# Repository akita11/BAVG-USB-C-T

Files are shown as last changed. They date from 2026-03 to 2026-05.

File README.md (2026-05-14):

# BAVG-USBC-T / BAVG-USBC-T-PD / BAVG-USBC-T-PDdiv

USB TypeｰCケーブル（両側）をツイストペア線と電源線として使用して、RS485等の差動伝送を行うことができます。
複数を直列（デージーチェーン）接続することで、マルチドロップのT型トポロジ接続にできます。

[M5Stack社のRS485 Unit](https://www.switch-science.com/products/6554)や[RS485M Unit](https://github.com/akita11/RS485M_Unit)等に接続して使用できます。
USB Type-Cケーブルの、データ線(D+/D-)をデータ送信用の差動対(A/B)、電源線を給電(V/G)に用います。

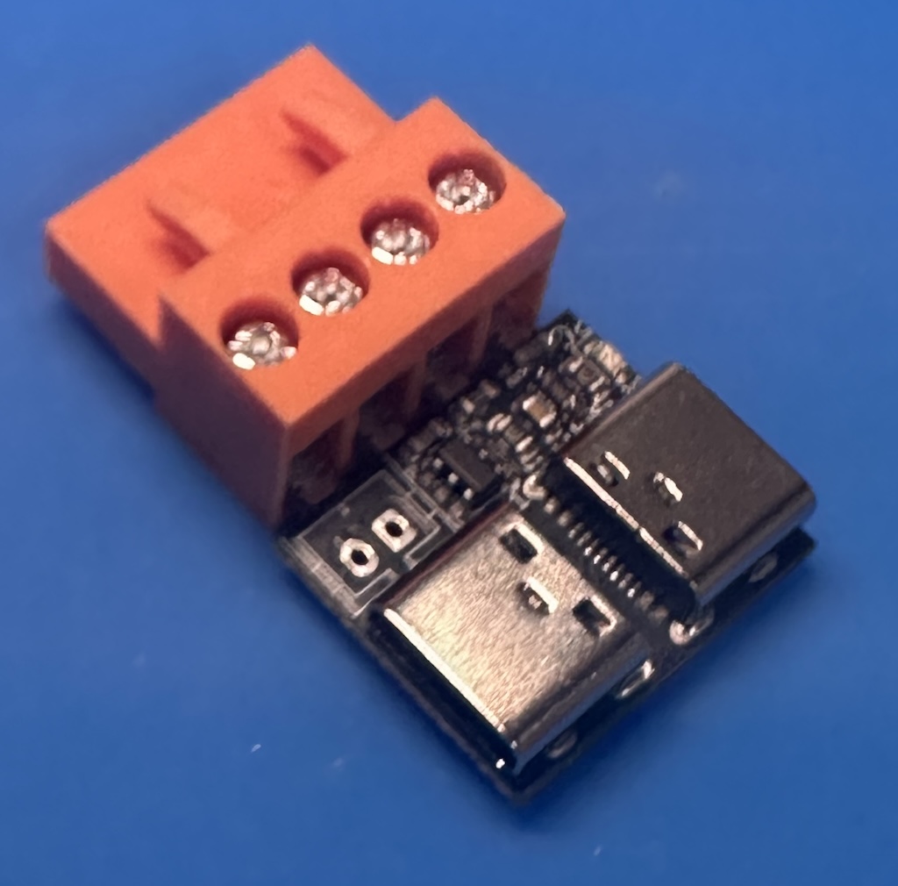
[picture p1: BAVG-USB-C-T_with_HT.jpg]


このページでは以下の3種類の情報をまとめています。

## BAVG-USBC-T

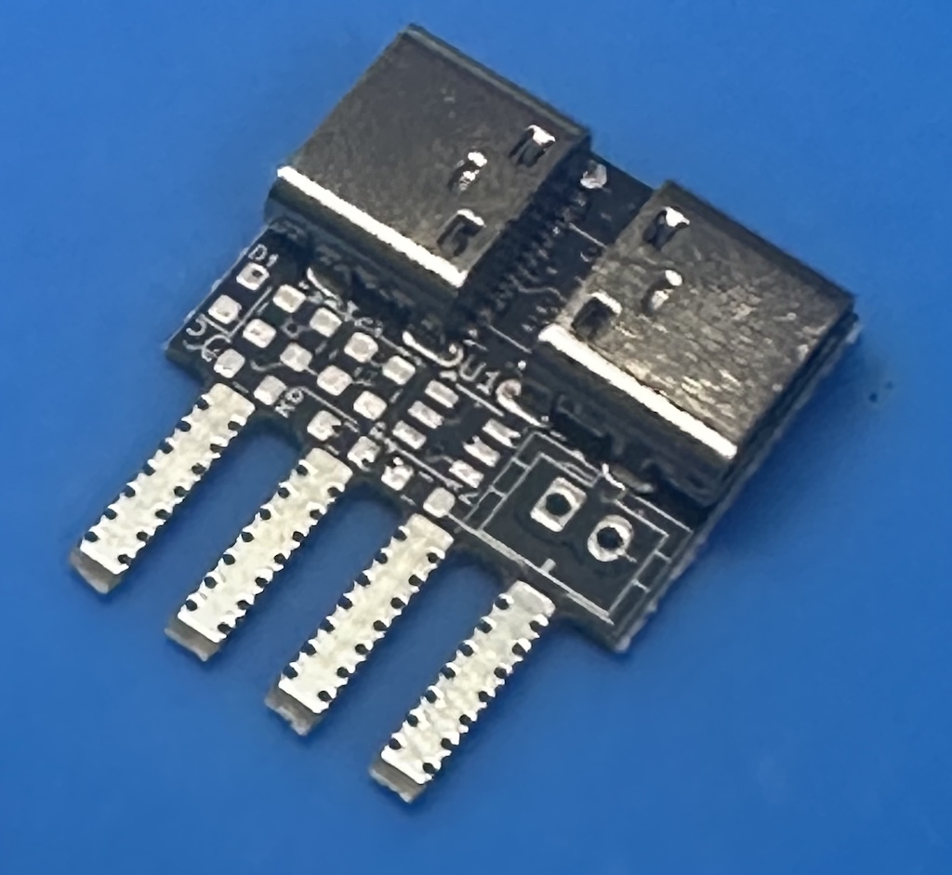
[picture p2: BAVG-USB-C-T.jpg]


両側のUSB Type-Cコネクタ間のデータ線(DP/DN)がA/B線と接続されていて、マルチドロップ型のデータ通信を行うことができます。

## BAVG-USBC-T-PD

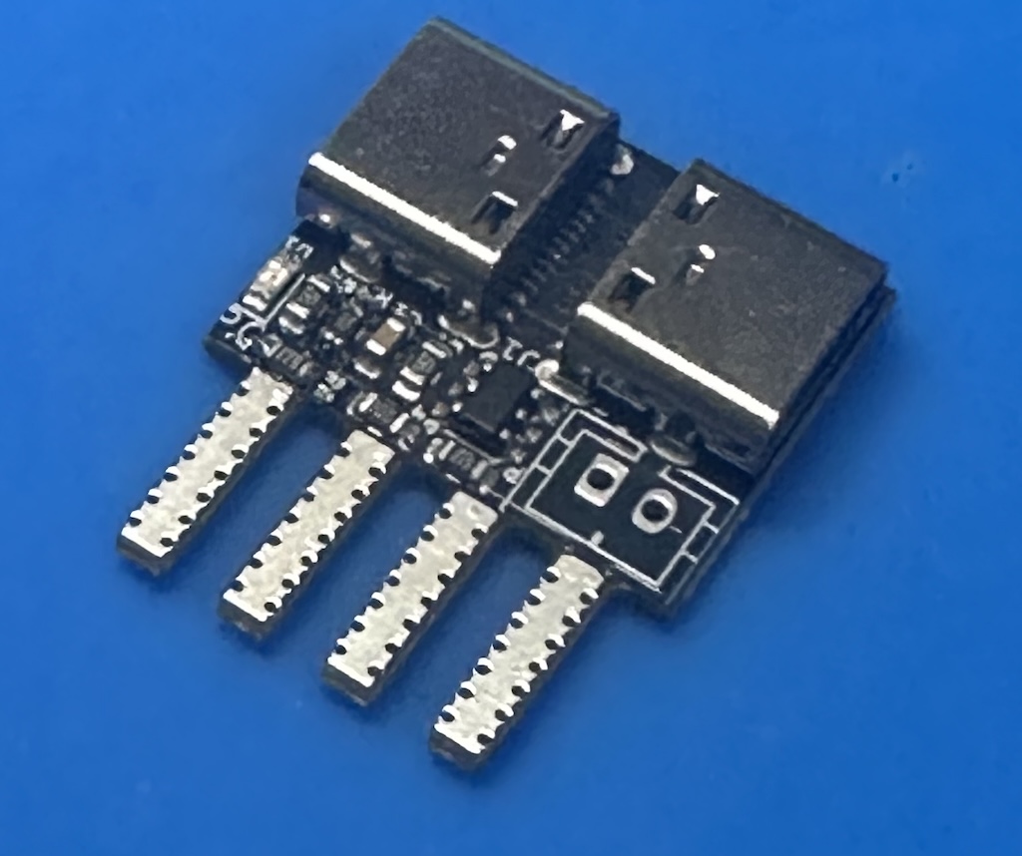
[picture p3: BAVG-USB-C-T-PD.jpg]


BAVG-USBC-T-PDではUSB PD (Power Derivery)の電圧設定機能があり、給電電圧を20Vまたは12Vに設定できます。
電圧設定が有効の場合はPG (Power Good)LEDが点灯します

また2つのUSBコネクタの通信線は接続されていないため、両側のUSBコネクタでのデータ通信を行うことはできません。
2つのコネクタでデータ通信を行う場合は、PD機能のない「BAVG-USBC-T」、またはPD給電コネクタが別にある「BAVG-USBC-T-PDdiv」を使用してください。

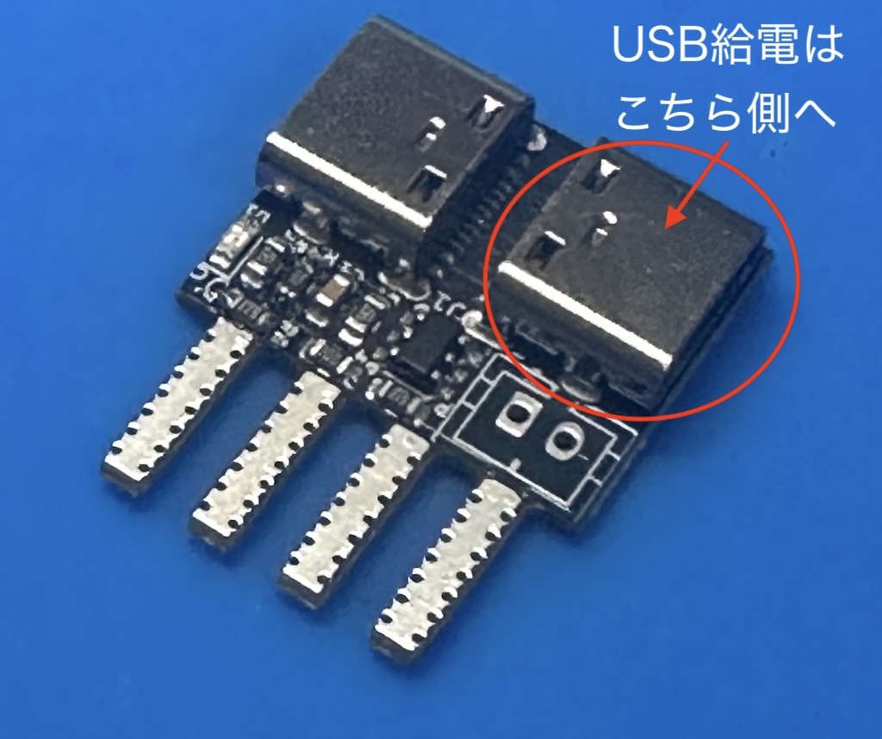
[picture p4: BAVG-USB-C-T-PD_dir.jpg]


**※USB PD電源からのUSB Type-Cケーブルは、必ず右側のUSB Type-Cコネクタ（この写真の赤丸側）へ接続してください。
（反対側に接続すると、RS485ラインのB/A端子がUSBケーブルのDP/DNに接続され、ACアダプタ等によってはQC制御によって供給電圧が変動する場合があり、高電圧の場合は機器が破損する場合があります）
またデータ通信は左側のUSB Type-Cコネクタのみに接続されています。**

通信経路と給電は以下の接続としてください。

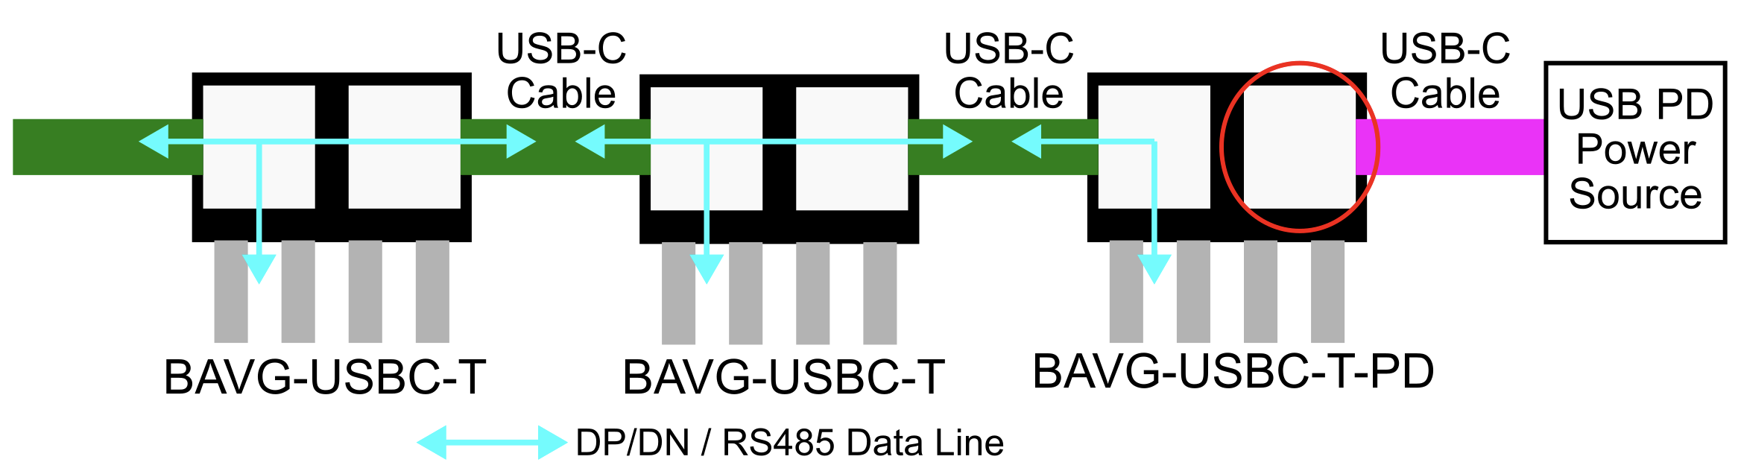
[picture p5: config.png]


### USB PD給電の設定

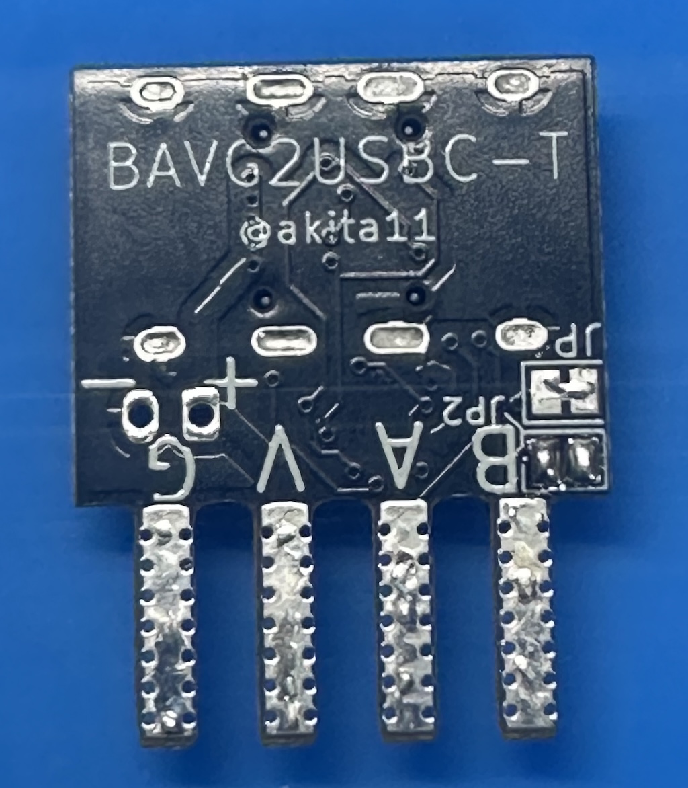
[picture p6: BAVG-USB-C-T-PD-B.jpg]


- JP1: USB PD電圧設定機能の有効無効設定
  - ショート（デフォルト） : 有効
  - オープン : =無効

- JP2でUSB PD給電電圧
  - オープン（デフォルト）: 20V
  - ショート : 12V

※USB PD電圧設定機能を有効にするのは、接続全体で1台のみとしてください。

※JP2の設定は、給電元（ACアダプタ等）へ要求する電圧で、実際に供給される電圧はUSB PD ACアダプタ等の仕様によります。
（例えば給電側の供給可能電圧が9V/15V/20Vの場合でJP2をショートした場合は9Vとなります）

## BAVG-USBC-T-PDdiv

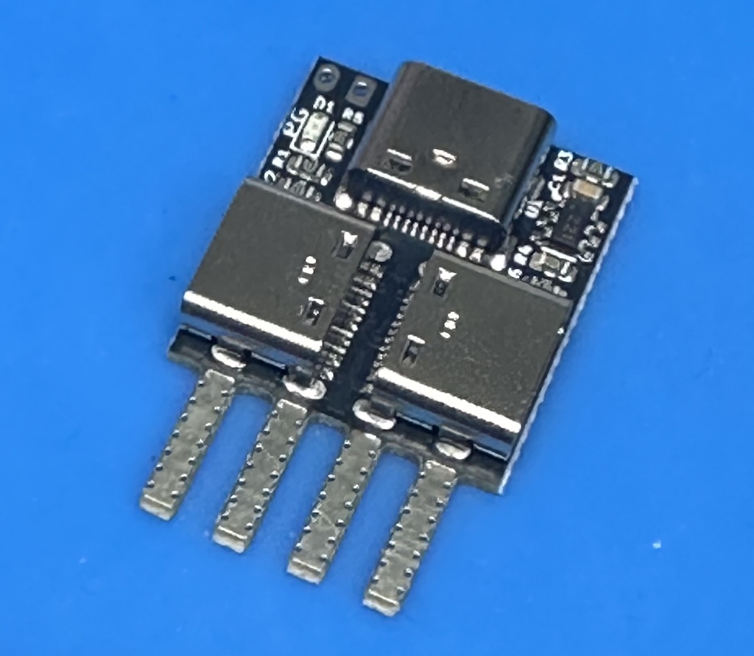
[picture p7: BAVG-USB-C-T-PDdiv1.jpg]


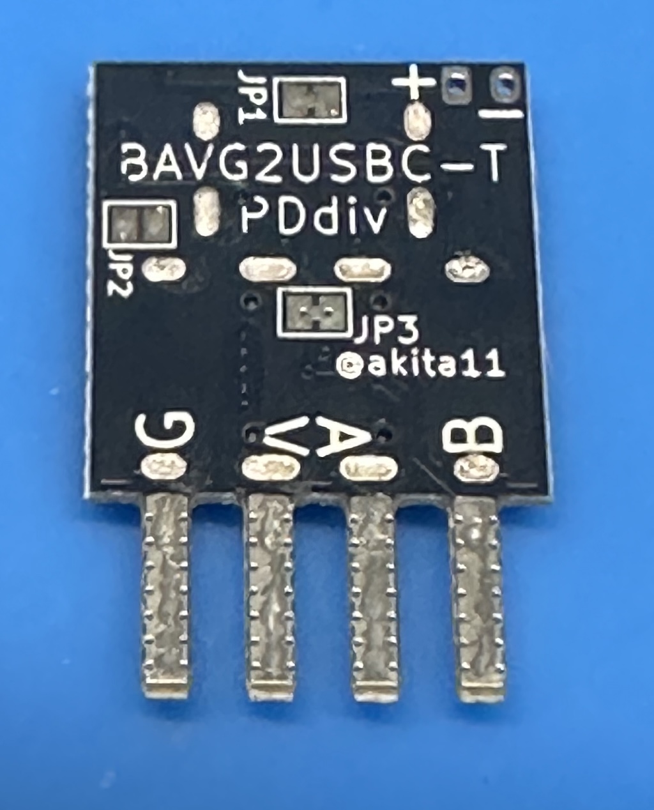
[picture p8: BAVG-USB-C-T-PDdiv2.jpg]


USB Type-Cコネクタが3つあり、1つは給電用（データ線の接続なし）、残り2つは「BAVG-USBC-T」と同様にデータ線（DP/DN）が接続されており、マルチドロップ型の通信を行うことができます。

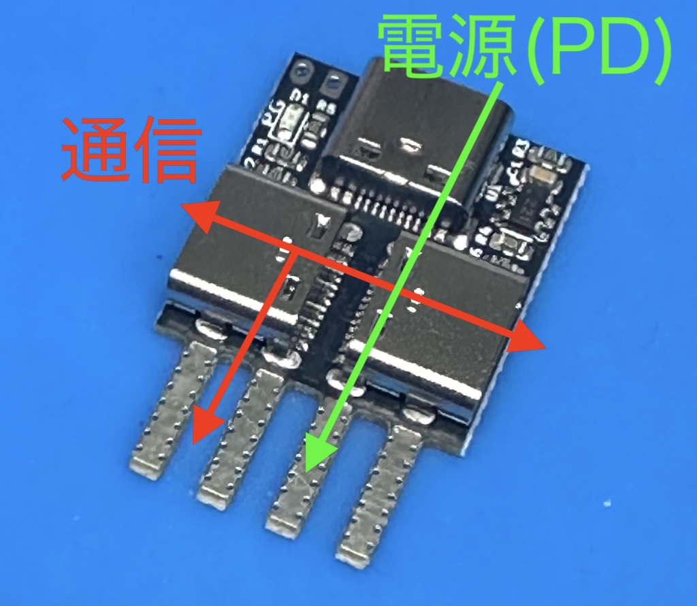
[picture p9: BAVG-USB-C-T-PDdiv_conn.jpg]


USB PDの電圧設定は「BAVG-USBC-T-PD」と同様です。

## Author

Junichi Akita (@akita11) / akita@ifdl.jp

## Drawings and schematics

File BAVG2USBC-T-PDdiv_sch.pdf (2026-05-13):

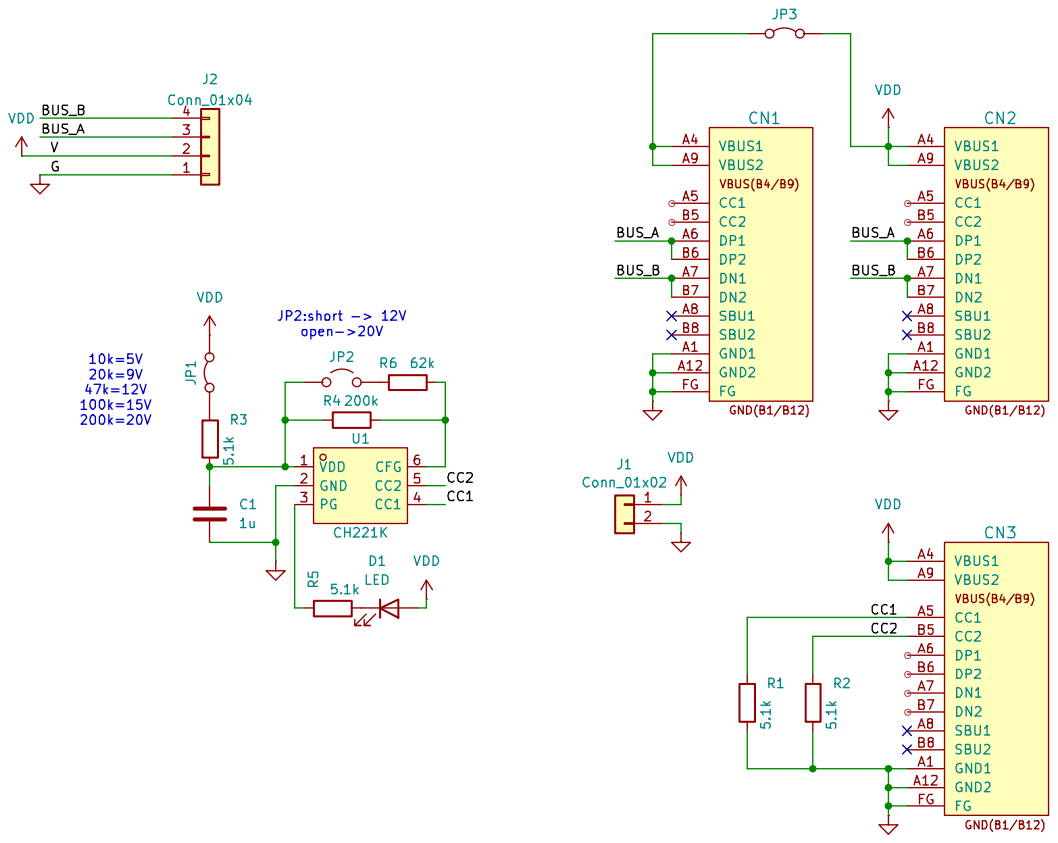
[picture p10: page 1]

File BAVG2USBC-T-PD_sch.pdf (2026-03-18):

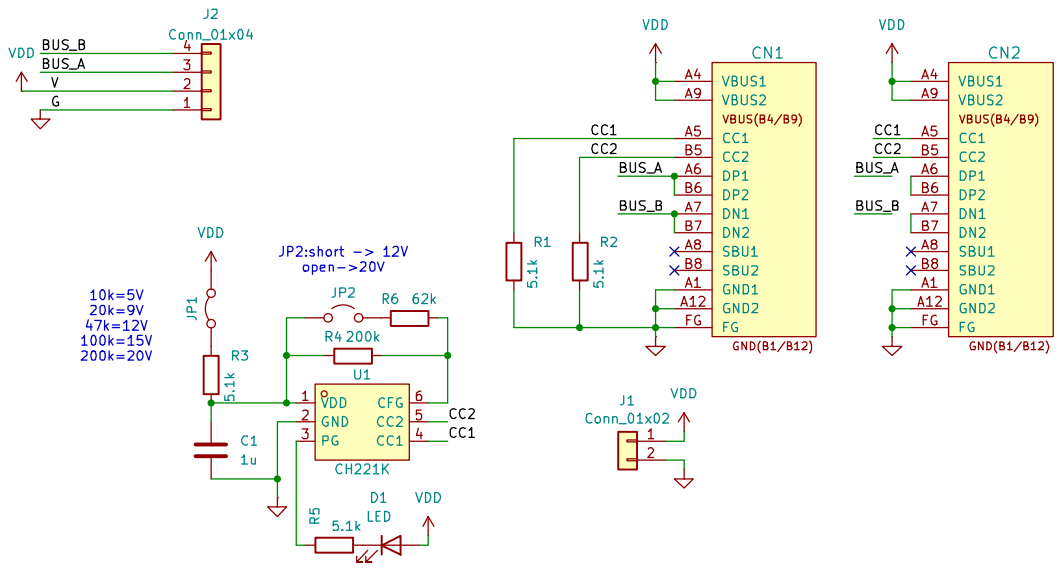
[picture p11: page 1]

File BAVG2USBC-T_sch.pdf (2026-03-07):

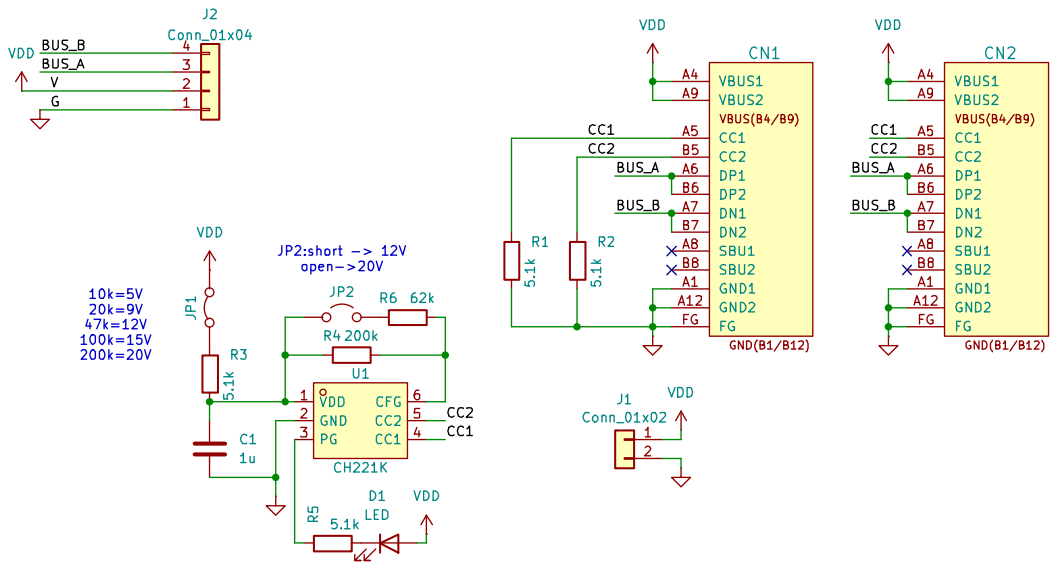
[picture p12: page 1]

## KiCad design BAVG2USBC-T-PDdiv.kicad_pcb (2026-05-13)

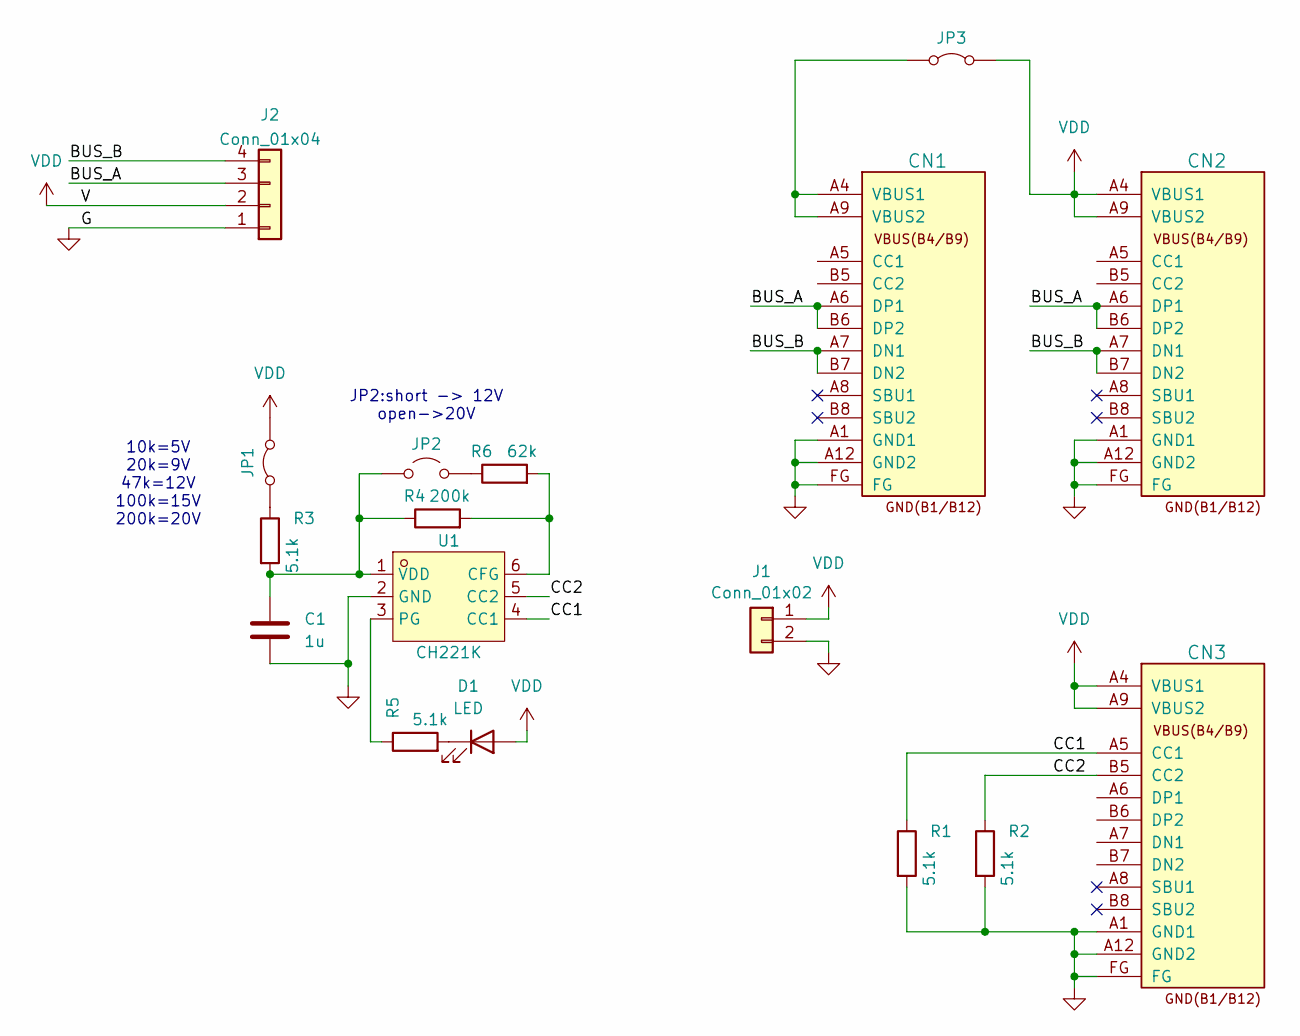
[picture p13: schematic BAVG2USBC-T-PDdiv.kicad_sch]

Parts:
C1: 1u; C_0603_1608Metric; LCSC C1588
CN1, CN2, CN3: CON_USB-C-16; USB-C_16P_TH; LCSC C165948
D1: LED; LED_0603_1608Metric; LCSC C2286
J1: Conn_01x02; JST_PH_B2B-PH-K_1x02_P2.00mm_Vertical
J2: Conn_01x04; CON_BAVG
JP1, JP3: Jumper_2_Bridged; SolderJumper-2_P1.3mm_Bridged_Pad1.0x1.5mm
JP2: Jumper_2_Open; SolderJumper-2_P1.3mm_Open_Pad1.0x1.5mm
R1, R2, R3, R5: 5.1k; R_0603_1608Metric; LCSC C23186
R4: 200k; R_0603_1608Metric; LCSC C25811
R6: 62k; R_0603_1608Metric; LCSC C23221
U1: CH221K; SOT-23-6_L2.9-W1.6-P0.95-LS2.8-BL-2; LCSC Part C5125736

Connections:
/BUS_A: CN1.A6 (DP1), CN1.B6 (DP2), CN2.A6 (DP1), CN2.B6 (DP2), J2.3
/BUS_B: CN1.A7 (DN1), CN1.B7 (DN2), CN2.A7 (DN1), CN2.B7 (DN2), J2.4
/CC1: CN3.A5 (CC1), R1.1, U1.4 (CC1)
/CC2: CN3.B5 (CC2), R2.1, U1.5 (CC2)
GND: C1.2, CN1.A1 (GND1), CN1.A12 (GND2), CN1.FG, CN2.A1 (GND1), CN2.A12 (GND2), CN2.FG, CN3.A1 (GND1), CN3.A12 (GND2), CN3.FG, J1.2, J2.1, R1.2, R2.2, U1.2 (GND)
unnamed: CN1.A4 (VBUS1), CN1.A9 (VBUS2), JP3.1 (A)
unnamed: D1.1 (K), R5.2
unnamed: JP1.1 (A), R3.1
unnamed: C1.1, JP2.1 (A), R3.2, R4.1, U1.1 (VDD)
unnamed: JP2.2 (B), R6.1
unnamed: R4.2, R6.2, U1.6 (CFG)
unnamed: R5.1, U1.3 (PG)
VDD: CN2.A4 (VBUS1), CN2.A9 (VBUS2), CN3.A4 (VBUS1), CN3.A9 (VBUS2), D1.2 (A), J1.1, J2.2, JP1.2 (B), JP3.2 (B)

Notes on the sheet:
10k=5V 20k=9V 47k=12V 100k=15V 200k=20V
JP2:short -> 12V open->20V

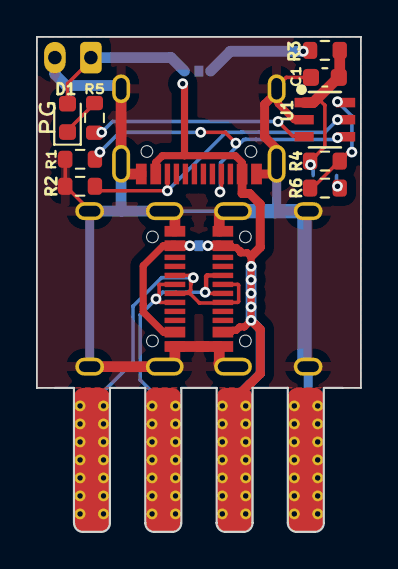
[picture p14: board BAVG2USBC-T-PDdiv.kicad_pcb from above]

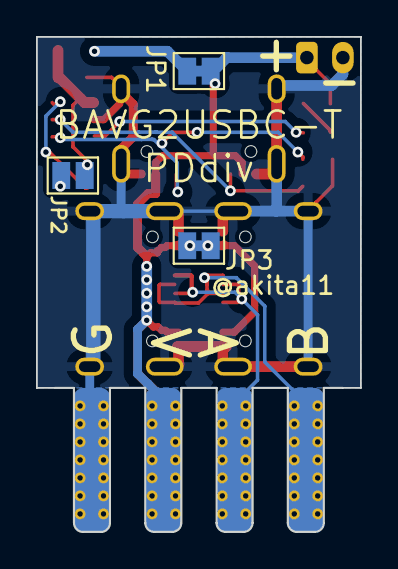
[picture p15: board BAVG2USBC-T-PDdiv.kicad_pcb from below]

Board: 2 copper layers, 18.0 x 27.5 mm, 17 parts (3 on the bottom side), 13 nets.

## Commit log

2026-03-18 add PD config
    [BAVG2USBC-T-PD.kicad_pcb, BAVG2USBC-T-PD.kicad_sch]
2026-05-13 add desc of PDdiv
    [BAVG2USBC-T-PDdiv.kicad_pcb, BAVG2USBC-T-PDdiv.kicad_sch]
